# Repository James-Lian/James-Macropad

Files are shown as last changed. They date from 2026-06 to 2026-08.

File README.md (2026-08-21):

# James-Macropad
A functional 3x4 layout macropad created following Hack Club's Hackpad guide. Designed to be used for digital art on Krita. 



## 💡 Features
- 3x4 layout, 12 Cherry MX keys
- rotary encoder
- OLED screen
- custom designed rotary encoder knurled knob
- 5 profiles (default + numpad + art + art-ctrl + art-shift)

## 🔌 PCB
Below is the schematic and PCB.
<br>



## 🧱 Case CAD model
The case is made up of two parts; a top section and a bottom section. The PCB is mounted plateless on the bottom section.    
   
I've also designed a custom knob to fit on the rotary encoder. I've taken inspiration from the knob on alexren's OrpheusPad, while adding some adjustments to ensure that the knob is smaller so it fits better between the rotary encoder and the keycaps.


## 📋 BOM
Here's everything needed to make this hackpad.
- 12x Cherry MX switches
- 12x DSA keycaps
- 6x M3x16mm screws
- 6x M3x5mmx4mm heatset inserts
- 1x 0.91 inch OLED display
- 1x EC11 rotary encoder
- 12x 1N4148 diodes
- 1x unsoldered Seeed XIAO RP2040
- + the custom-designed case (3 printed parts: bottom, top, knob)
 
## ⚙️ Assembly
1. Solder the diodes, Seeeduino, OLED, and rotary encoder to the PCB (recommended in that order)
2. Install CircuitPython on the Seeeduino, and then KMK, as well as the adafruit_display_text, adafruit_framebuf.mpy, adafruit_displayio_ssd1306.mpy, and adafruit_ssd1306.mpy libraries (recommended to do this before the "Middle" 3d printed part blocks the Seeeduino bootloader button)
5. Push the 12 Cherry MX switches through the holes in the "Middle" 3d printed part, and then solder the backs of the switches to the PCB
6. Heatset the inserts into the "Bottom" 3d printed part (4 in total) and install the screws from the top.
<br>


## ⭐ How to Use
Below is a screenshot of the keymap layers (arranged in a 3x4 layout), along with a screenshot of KEY_LABELS that denote what each key does.
<br>
The MO keys temporarily change the macropad's layers when holding them down. The TG keys toggle between the default and art layers. On the art layer (layer 2), holding MO(3) toggles the ART-CTRL layer, essentially acting like a CTRL modifier key and allowing the user to access CTRL-related commands. Holding both the MO(3) and MO(4) keys toggles the ART-CTRL-SHIFT layer, which allows you to access CTRL-SHIFT-related commands and other additional keys. 
<br>



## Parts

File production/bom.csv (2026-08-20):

Designator | Footprint | Quantity | Value | LCSC Part #
D1, D10, D11, D12, D2, D3, D4, D5, D6, D7, D8, D9 | D_DO-35_SOD27_P7.62mm_Horizontal | 12 | 1N4148
SW1, SW10, SW11, SW12, SW2, SW3, SW4, SW5, SW6, SW7, SW8, SW9 | SW_Cherry_MX_1.00u_PCB_(3D_STEP) | 12 | SW_Push
SW13 | RotaryEncoder_Alps_EC11E-Switch_Vertical_H20mm | 1 | RotaryEncoder_Switch
U1 | XIAO-Generic-Hybrid-14P-2.54-21X17.8MM | 1 | MOUDLE-SEEEDUINO-XIAO
U2 | ER_OLEDM0.91_1x-I2C_(3D_STEP) | 1 | ER_OLEDM0.91_1x-I2C

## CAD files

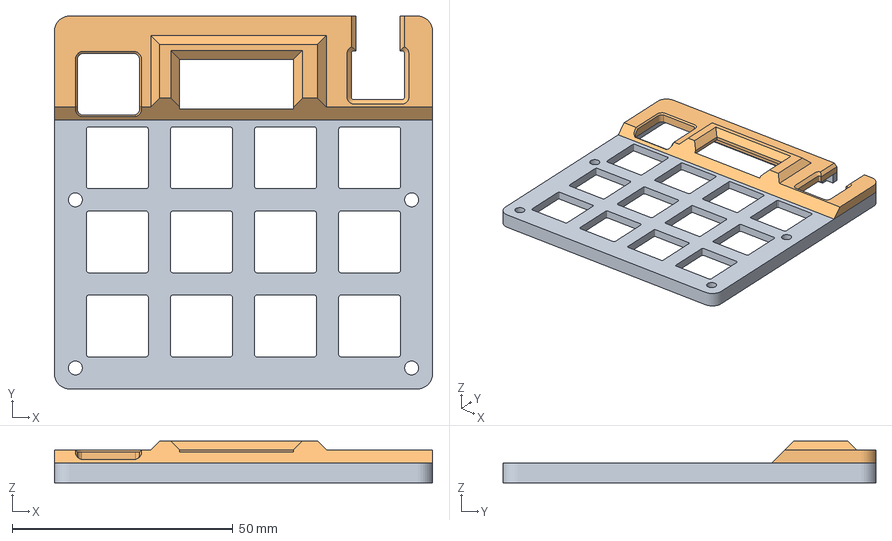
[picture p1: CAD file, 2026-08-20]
cad/Middle.3mf
85.7 x 84.5 x 9.50 mm
Top cover

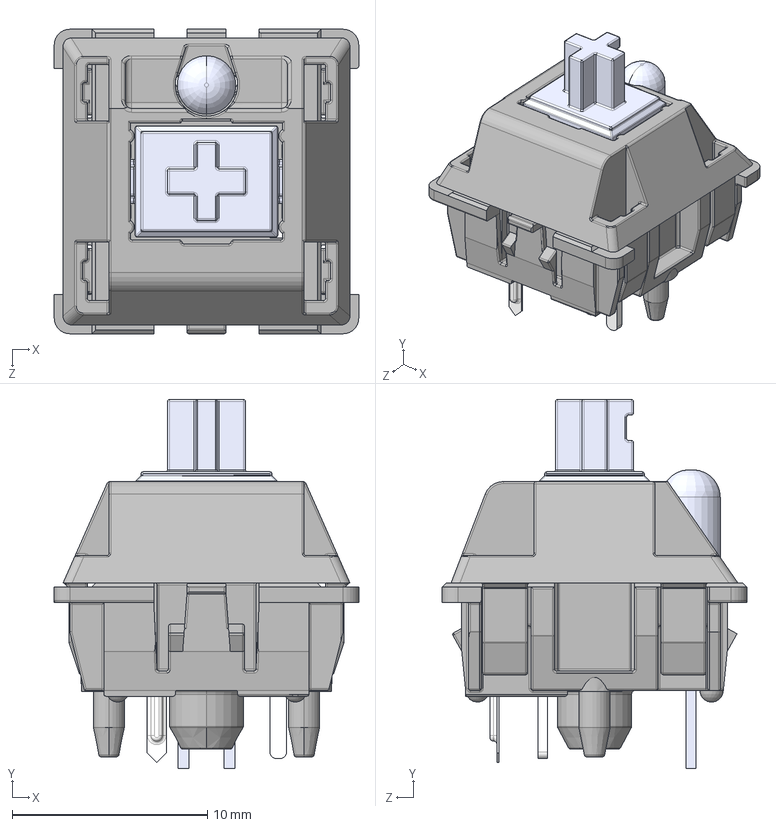
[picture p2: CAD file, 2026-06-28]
pcb/kicad_care_package/MX .STEP
15.6 x 18.9 x 15.6 mm
MX 轴 按键′_ü___¨1
MX 轴 轴体áì_¨￠¨__
MX粣 拸簽LEDLEDLED
MX轴 轴体 底部 μ×2__默认_á2____è_
针脚___默认__è_

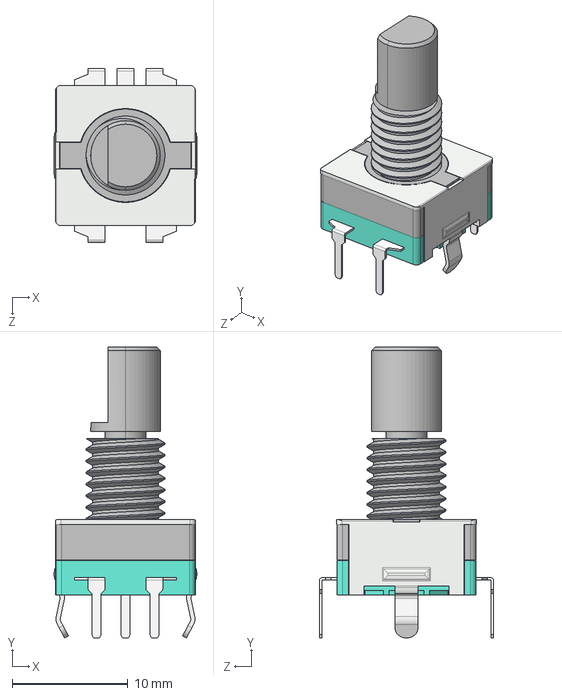
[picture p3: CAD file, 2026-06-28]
pcb/rotary_encoder/rotary_encoder.STEP
12.3 x 25.1 x 15.0 mm

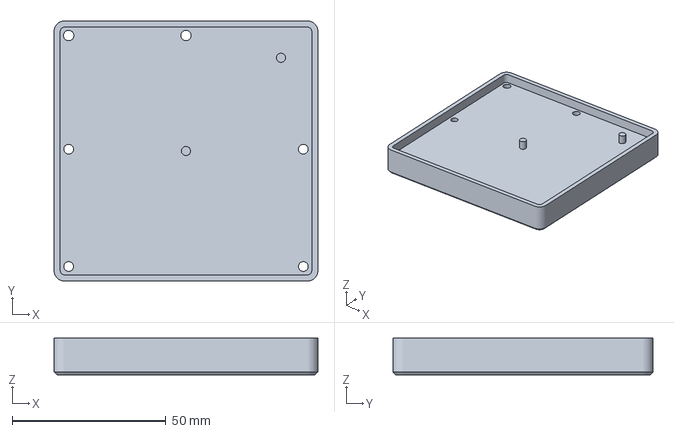
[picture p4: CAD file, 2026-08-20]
cad/Bottom.3mf
85.7 x 84.5 x 12.0 mm

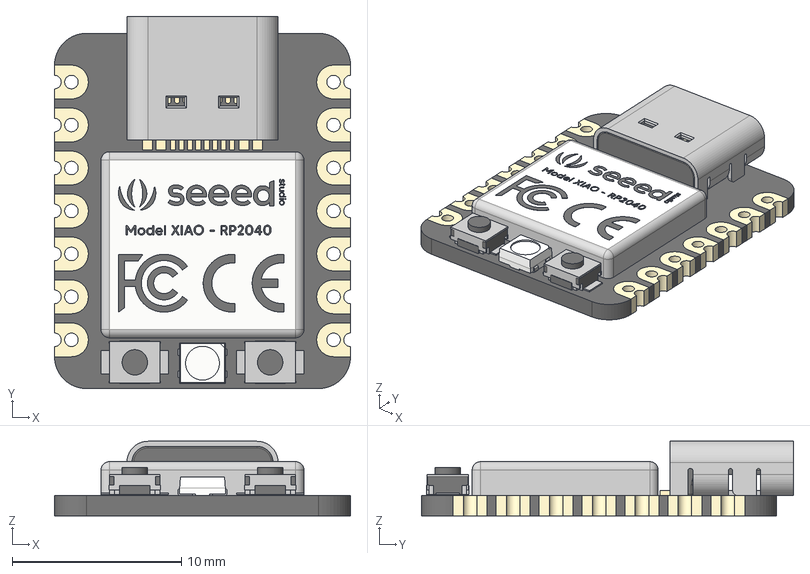
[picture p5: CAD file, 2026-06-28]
pcb/kicad_care_package/Seeed Studio XIAO RP2040 v26.step
17.5 x 22.0 x 4.40 mm
type-c v2
smd_button v3
DOUT
DIN
VSS
VDD
smd_button v3(Mirror)

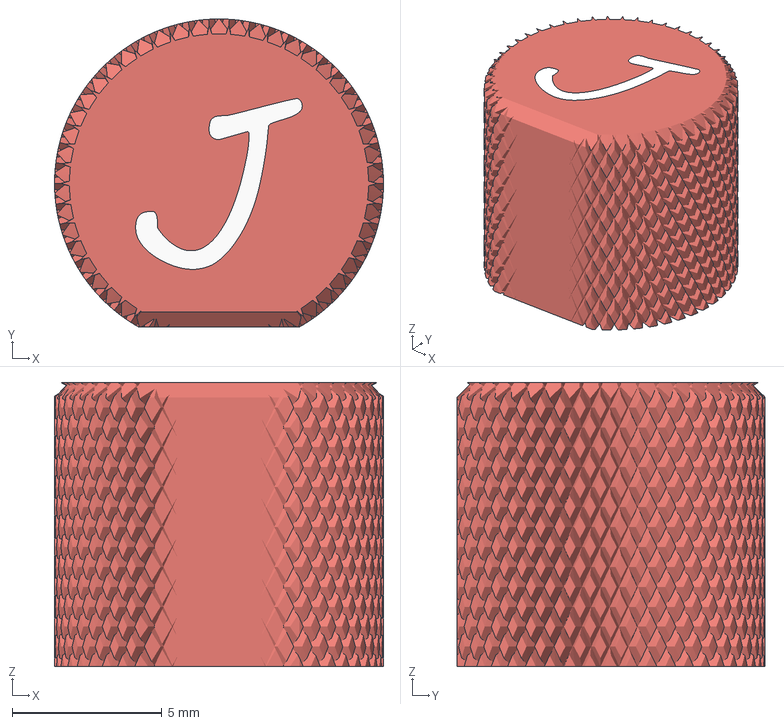
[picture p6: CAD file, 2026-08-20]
cad/Knob.3mf
11.0 x 10.3 x 9.50 mm

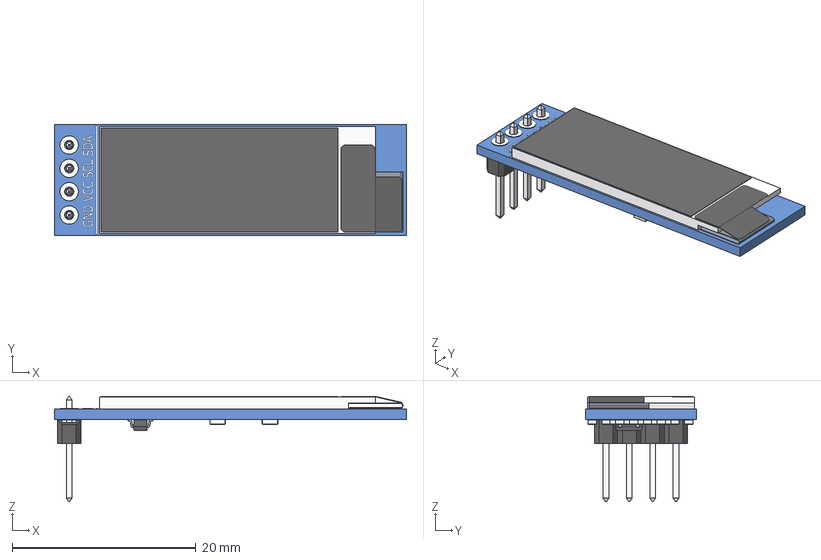
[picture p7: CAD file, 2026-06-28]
pcb/kicad_care_package/OLED_0.91_128x32.stp
38.3 x 12.1 x 11.5 mm
OLED_0.91_128x32
Pin Header 4 x 1 TH 2.54mm Pitch
RESC-0603 x 13
2SD0601A

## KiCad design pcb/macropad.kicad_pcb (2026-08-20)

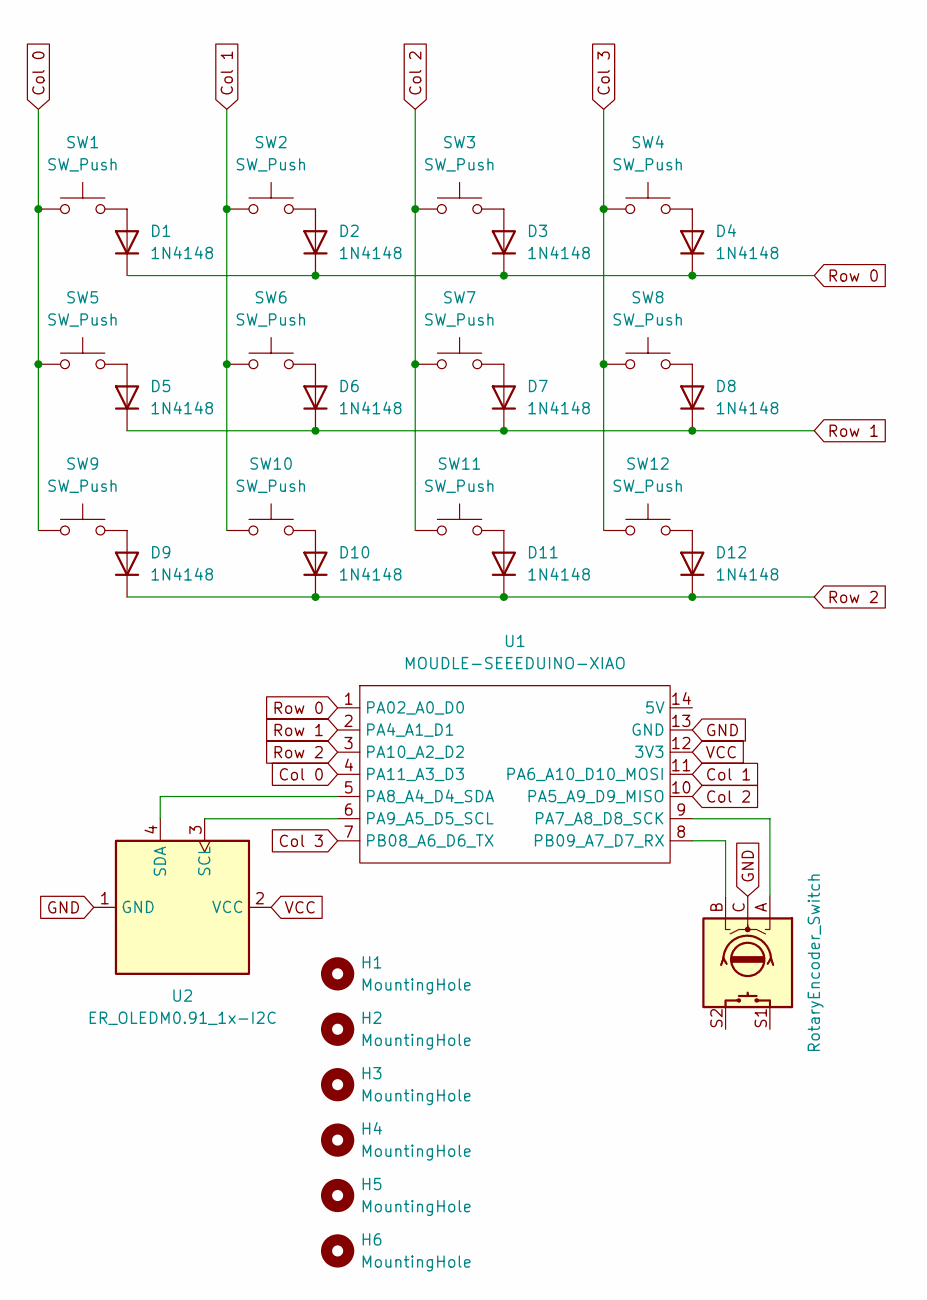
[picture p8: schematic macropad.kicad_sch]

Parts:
D1, D2, D3, D4, D5, D6, D7, D8, D9, D10, D11, D12: 1N4148; D_DO-35_SOD27_P7.62mm_Horizontal
H1, H2, H3, H4, H5, H6: MountingHole; MountingHole_3.2mm_M3
SW1, SW2, SW3, SW4, SW5, SW6, SW7, SW8, SW9, SW10, SW11, SW12: SW_Push; SW_Cherry_MX_1.00u_PCB_(3D_STEP)
SW13: RotaryEncoder_Switch; RotaryEncoder_Alps_EC11E-Switch_Vertical_H20mm
U1: MOUDLE-SEEEDUINO-XIAO; XIAO-Generic-Hybrid-14P-2.54-21X17.8MM
U2: ER_OLEDM0.91_1x-I2C; ER_OLEDM0.91_1x-I2C_(3D_STEP)

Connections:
Col 0: SW1.1, SW5.1, SW9.1, U1.4 (PA11_A3_D3)
Col 1: SW2.1, SW6.1, SW10.1, U1.11 (PA6_A10_D10_MOSI)
Col 2: SW3.1, SW7.1, SW11.1, U1.10 (PA5_A9_D9_MISO)
Col 3: SW4.1, SW8.1, SW12.1, U1.7 (PB08_A6_D6_TX)
GND: SW13.C, U1.13 (GND), U2.1 (GND)
unnamed: D1.2 (A), SW1.2
unnamed: D2.2 (A), SW2.2
unnamed: D3.2 (A), SW3.2
unnamed: D4.2 (A), SW4.2
unnamed: D5.2 (A), SW5.2
unnamed: D6.2 (A), SW6.2
unnamed: D7.2 (A), SW7.2
unnamed: D8.2 (A), SW8.2
unnamed: D9.2 (A), SW9.2
unnamed: D10.2 (A), SW10.2
unnamed: D11.2 (A), SW11.2
unnamed: D12.2 (A), SW12.2
unnamed: SW13.A, U1.9 (PA7_A8_D8_SCK)
unnamed: U1.5 (PA8_A4_D4_SDA), U2.4 (SDA)
unnamed: U1.6 (PA9_A5_D5_SCL), U2.3 (SCL)
unnamed: SW13.B, U1.8 (PB09_A7_D7_RX)
Row 0: D1.1 (K), D2.1 (K), D3.1 (K), D4.1 (K), U1.1 (PA02_A0_D0)
Row 1: D5.1 (K), D6.1 (K), D7.1 (K), D8.1 (K), U1.2 (PA4_A1_D1)
Row 2: D9.1 (K), D10.1 (K), D11.1 (K), D12.1 (K), U1.3 (PA10_A2_D2)
VCC: U1.12 (3V3), U2.2 (VCC)

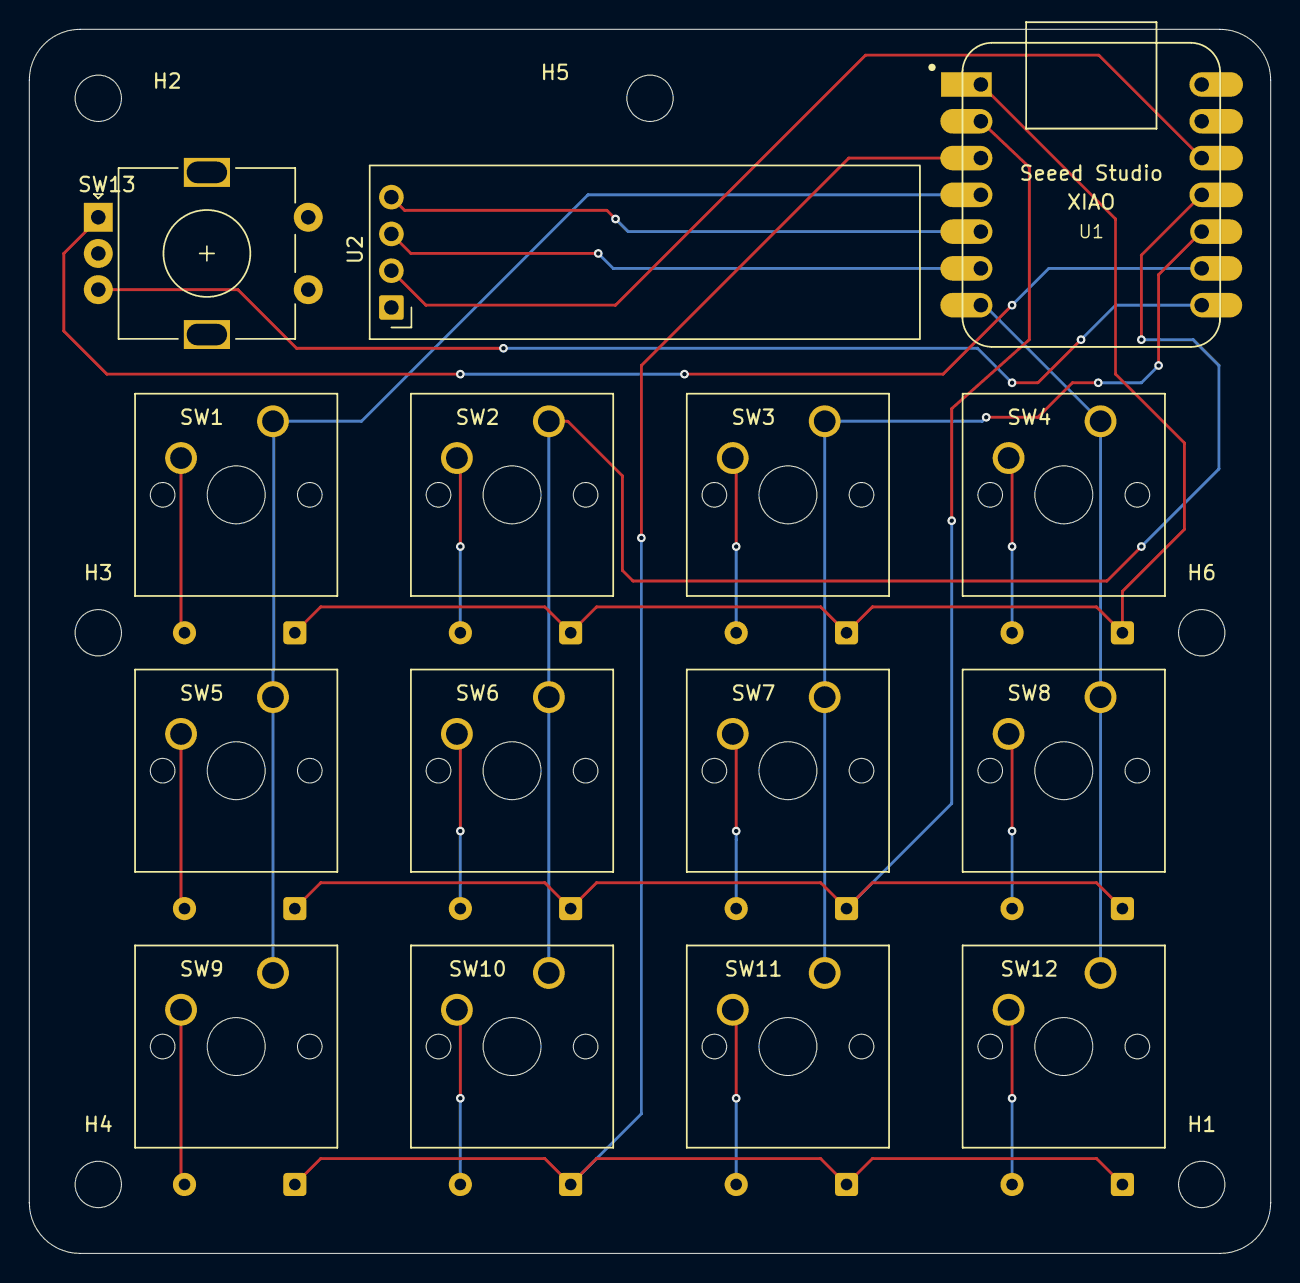
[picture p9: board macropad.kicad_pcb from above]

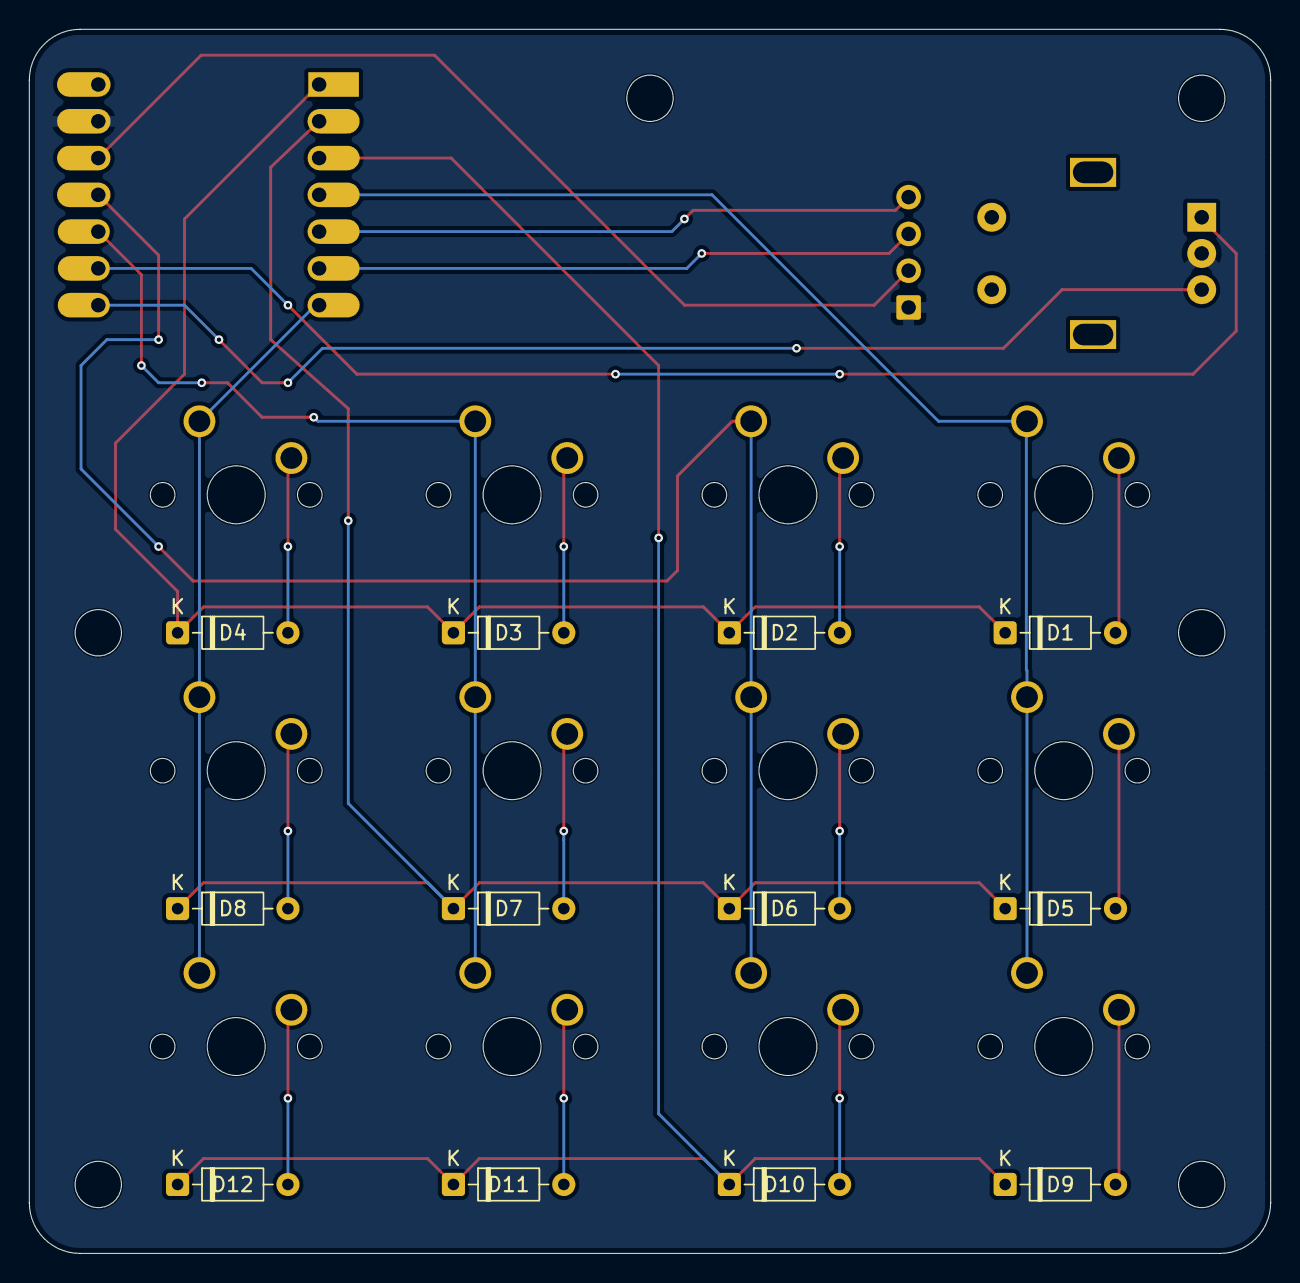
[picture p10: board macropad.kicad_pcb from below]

Board: 2 copper layers, 85.7 x 84.5 mm, 33 parts (12 on the bottom side), 25 nets.

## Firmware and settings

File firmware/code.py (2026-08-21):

print("Starting")

import board
import busio
from kmk.kmk_keyboard import KMKKeyboard
from kmk.keys import KC
from kmk.scanners import DiodeOrientation
from kmk.modules.layers import Layers
from kmk.modules.encoder import EncoderHandler
from kmk.modules.mouse_keys import MouseKeys
from kmk.extensions.media_keys import MediaKeys
from kmk.extensions.display import Display, TextEntry
from kmk.extensions.display.ssd1306 import SSD1306

import time

keyboard = KMKKeyboard()
layers = Layers()
encoder_handler = EncoderHandler()
mousekeys = MouseKeys(
    max_speed = 10,
    acc_interval = 20,
    move_step = 1
)

# Using standard KMK setup 
keyboard.col_pins = (board.D3, board.D10, board.D9, board.D6)
keyboard.row_pins = (board.D0, board.D1, board.D2)
keyboard.diode_orientation = DiodeOrientation.COL2ROW

KEY_LABELS = {
    0: {
        0: "ESC", 1: "F2", 2: "F11", 3: "F12", 
        4: "HOME", 5: "END", 6: "UP", 7: "TG(Default)", 
        8: "MO(Numpad)", 9: "LEFT", 10: "DOWN", 11: "RIGHT"
    },
    1: {
        0: "Backspace", 1: "7", 2: "8", 3: "9", 
        4: "Enter", 5: "4", 6: "5", 7: "6", 
        8: "MO(Numpad)", 9: "1", 10: "2", 11: "3"
    },
    2: {
        0: "A", 1: "S", 2: "E", 3: "R", 
        4: "Del", 5: "/", 6: "B", 7: "TG(Art)", 
        8: "Ctrl", 9: "3", 10: "Space", 11: "M"
    },
    3: {
        0: "Ctrl+A", 1: "Ctrl+S", 2: "Ctrl+E", 3: "Ctrl+T", 
        4: "Ctrl+Shift", 5: "Ctrl+Z", 6: "Ctrl+G", 7: "Ctrl+J", 
        8: "Ctrl", 9: "Ctrl+X", 10: "Ctrl+C", 11: "Ctrl+R"
    },
    4: {
        0: "Ctrl+Shift+A", 1: "Ctrl+Shift+S", 2: "Minus", 3: "Plus", 
        4: "Ctrl+Shift", 5: "Ctrl+Shift+Z", 6: "Ctrl+Shift+I", 7: "PgUp", 
        8: "Ctrl", 9: "C+S+R", 10: "F11", 11: "PgDn"
    },
}

keyboard.keymap = [
    # Layer 0: Standard
    [
        KC.ESCAPE, KC.F2,   KC.F11,   KC.F12,
        KC.HOME,   KC.END,  KC.UP,    KC.TG(2), 
        KC.MO(1),  KC.LEFT, KC.DOWN,  KC.RIGHT
    ],
    # Layer 1: Standard modifier layer
    [
        KC.BSPACE, KC.KP_7, KC.KP_8, KC.KP_9, 
        KC.ENTER,  KC.KP_4, KC.KP_5, KC.KP_6, 
        KC.TRNS,   KC.KP_1, KC.KP_2, KC.KP_3
    ],
    # Layer 2: Art
    [
        KC.A,     KC.S,     KC.E,     KC.R, # or Escmm, R, Slash, E
        KC.DEL,   KC.SLASH, KC.B,     KC.TG(2), # or Shift, Shift, B, M
        KC.MO(3), KC.N3,    KC.SPACE, KC.M # SPACE, layer toggle back to std
    ],
    # Layer 3: Art (CTRL) modifier layer
    [
        KC.LCTRL(KC.A), KC.LCTRL(KC.S), KC.LCTRL(KC.E), KC.LCTRL(KC.T),
        KC.MO(4),       KC.LCTRL(KC.Z), KC.LCTRL(KC.G), KC.LCTRL(KC.J),
        KC.TRNS,        KC.LCTRL(KC.X), KC.LCTRL(KC.C), KC.LCTRL(KC.R)
    ],
    # Layer 4: Art (SHIFT) modifier layer
    [
        KC.LCTRL(KC.LSHIFT(KC.A)), KC.LCTRL(KC.LSHIFT(KC.S)), KC.MINUS,                  KC.PLUS,
        KC.TRNS,                   KC.LCTRL(KC.LSHIFT(KC.Z)), KC.LCTRL(KC.LSHIFT(KC.I)), KC.PGUP,
        KC.TRNS,                   KC.LCTRL(KC.LSHIFT(KC.R)), KC.F11,                    KC.PGDN
    ]
]

LYR_STD, LYR_ART = 0, 1

# OLED Setup 
i2c_bus = board.I2C() 
driver = SSD1306(i2c=i2c_bus)

display = Display(
    display=driver,
    width=128,
    height=32,
    flip = False,
    brightness=0.8,
    brightness_step=0.1,
    dim_time=20,
    dim_target=0.1,
    off_time=60,
    powersave_dim_time=10,
    powersave_dim_target=0.1,
    powersave_off_time=30,
)

input_display_entry = TextEntry(text=" ", x=0, y=0, y_anchor="T")
layer_display_num = TextEntry(text='0:', x=32, y=31, y_anchor="B")
layer_display_name = TextEntry(text='DEFAULT', x=50, y=31, y_anchor="B")
LAYER_NAMES = {
    0: "DEFAULT", 
    1: "NUMPAD",
    2: "ART",
    3: "ART-CTRL",
    4: "ART-CTRL-SHIFT"
}

display.entries = [
    input_display_entry,
    TextEntry(text='Layer', x=0, y=31, y_anchor="B"),
    layer_display_num,
    layer_display_name,
]
keyboard.extensions.append(display)

class OLEDManager:
    def __init__(self):
        self.held_keys = []
        self.last_text = ""
        self.last_input_time = time.monotonic()
        self.is_cleared = False
        self.last_layer = 0

    def process_key(self, keyboard, key, is_pressed, int_coord=None, *args, **kwargs):
        # coord is integer representing physical key location
        coord = int_coord 
        if coord is None and "coord_int" in kwargs:
            coord = kwargs["coord_int"]
        if coord is None and len(args) > 0 and isinstance(args[0], int):
            coord = args[0]

        # track physical keys going up and down
        if coord is not None:
            if is_pressed: # press events
                if coord not in self.held_keys:
                    self.held_keys.append(coord)
            else: # release events
                if coord in self.held_keys:
                    self.held_keys.remove(coord)

        return key

    # constantly monitors keyboard for layer changes, etc.
    def after_matrix_scan(self, keyboard, *args, **kwargs):
        current_time = time.monotonic()
        new_text = None
        top_layer = max(keyboard.active_layers) if keyboard.active_layers else 0

        if top_layer != self.last_layer:
            top_layer = max(keyboard.active_layers) if keyboard.active_layers else 0
            layer_display_num.text = f"{top_layer}: "
            layer_display_name.text = f"{LAYER_NAMES.get(top_layer, 'UNKNOWN')}"

        # 1. If keys are held, grab the label
        if len(self.held_keys) > 0:
            active_coord = self.held_keys[-1]
            label = KEY_LABELS.get(top_layer, {}).get(active_coord, "Key")
            new_text = f"{label}"
            
            # Reset timer and clear flag while actively holding keys
            self.last_input_time = current_time
            self.is_cleared = False

        # 2. If no keys are held, check if 5 seconds have passed since release
        elif not self.is_cleared and (current_time - self.last_input_time >= 5):
            self.is_cleared = True
            new_text = " "

        # 3. Apply changes if there's something new to show/clear
        if new_text is not None and new_text != self.last_text:
            # prevent rerenders of modifier keys after rendering valid key press
            if (self.last_text in KEY_LABELS[1].values()) and (new_text == "MO(Numpad)"):
                return
            if (self.last_text in KEY_LABELS[3].values()) and (new_text == "Ctrl"):
                return
            if (self.last_text in KEY_LABELS[4].values()) and (new_text == "Ctrl+Shift" and self.last_text != "Ctrl"):
                return
            
            input_display_entry.text = new_text
            self.last_text = new_text

            self.last_layer = top_layer
            try:
                display.render(keyboard)
            except AttributeError:
                pass
        else:
            if top_layer != self.last_layer:
                self.last_layer = top_layer
                try:
                    display.render(keyboard)
                except AttributeError:
                    pass


    # Required boilerplate
    def during_bootup(self, *args, **kwargs): pass
    def before_matrix_scan(self, *args, **kwargs): pass
    def before_hid_send(self, *args, **kwargs): pass
    def after_hid_send(self, *args, **kwargs): pass
    def on_powersave_enable(self, *args, **kwargs): pass
    def on_powersave_disable(self, *args, **kwargs): pass

keyboard.modules = [
    OLEDManager(),
    layers, 
    encoder_handler,
    mousekeys,
]
keyboard.extensions.append(MediaKeys())

# Encoder Setup
encoder_handler.pins = (
    (board.D7, board.D8, None),
)

encoder_handler.map = [
    ((KC.VOLD, KC.VOLU),),
    ((KC.MS_UP, KC.MS_DN),)
]

if __name__ == '__main__':
    keyboard.go()

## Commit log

2026-06-28 Add CAD .step files
    [bottom_(to_print).step, knob_(to_print).step, top_(to_print).step]
2026-06-28 Add BOM.csv
    Generated from KiCAD.
    [BOM.csv]
2026-08-20 Update middle plate to include cutout for Seeduino
    [Middle.3mf]
2026-08-20 Rectify incorrect file upload
    [Middle.3mf]
2026-08-20 Upload production with correction
    [bom.csv, designators.csv, positions.csv]
2026-08-20 Upload pcb with minor correction
    [MX .STEP, OLED_0.91_128x32.stp, Seeed Studio XIAO RP2040 v26.step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]
